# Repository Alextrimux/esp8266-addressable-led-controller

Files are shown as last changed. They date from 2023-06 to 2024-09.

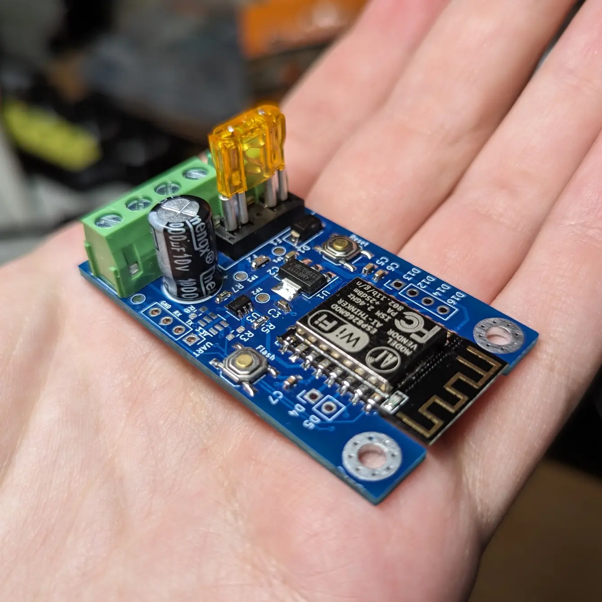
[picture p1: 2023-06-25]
pictures/board_1.jpg

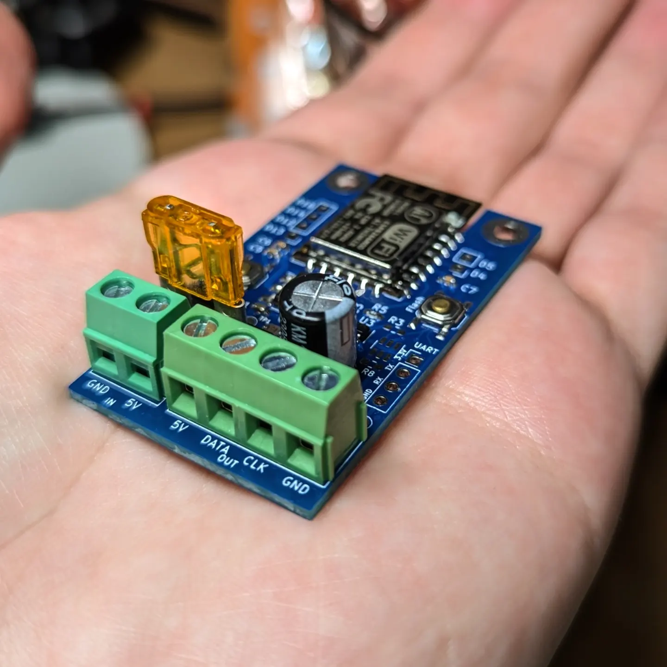
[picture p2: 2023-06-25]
pictures/board_2.jpg

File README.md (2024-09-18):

# esp8266-addressable-led-controller
The small hardware project of the addressable led controller on esp8266.

It is designed especially for using [WLED firmware](https://github.com/Aircoookie/WLED).

Features:
 - two-channel output for LED strip
 - reverse polarity protection
 - plug-in fuse
 - additional pins for extension

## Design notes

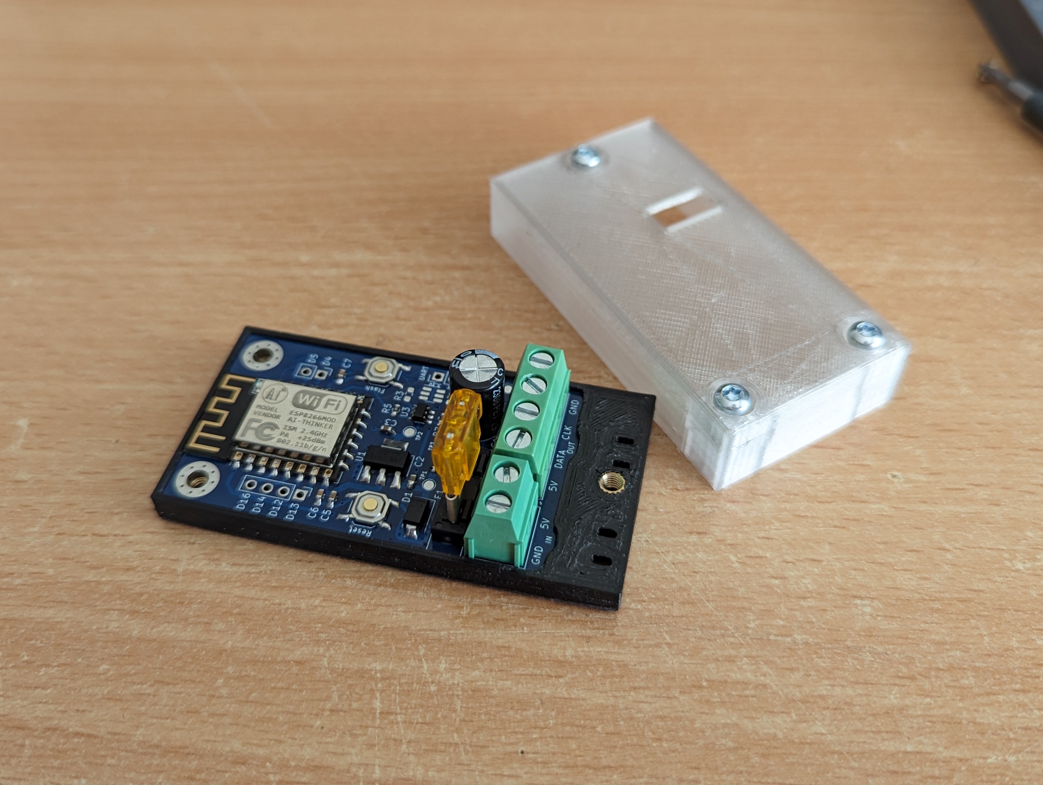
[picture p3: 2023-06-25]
pictures/case_open.jpg

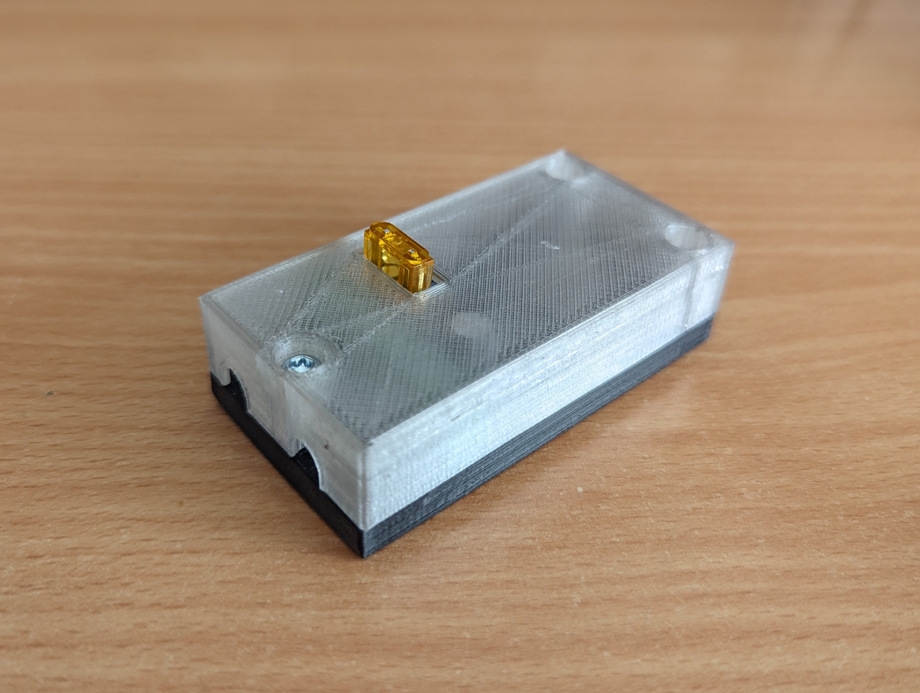
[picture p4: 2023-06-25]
pictures/case.jpg

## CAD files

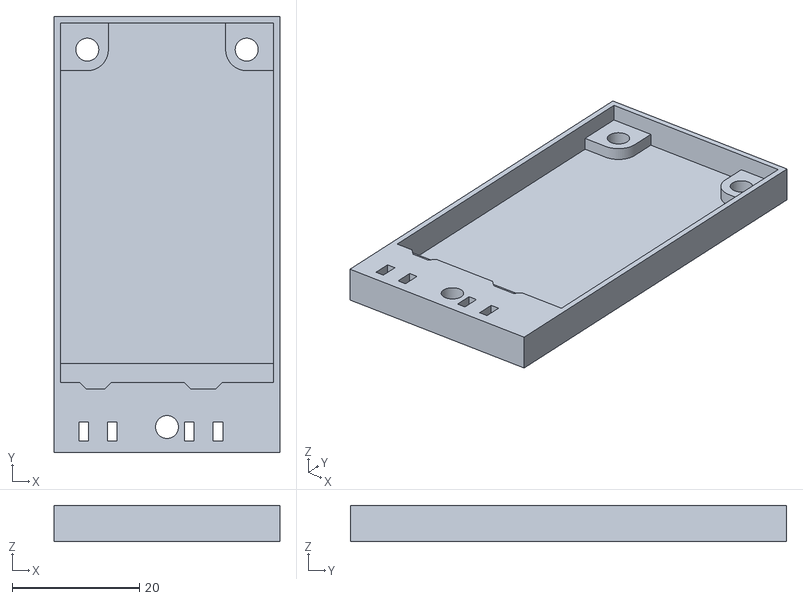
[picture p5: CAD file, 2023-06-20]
case/led-ctrl-top-v1.1.stl
35.4 x 68.4 x 5.70

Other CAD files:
case/led-ctrl-bottom.stl
case/esp8266-addressable-led-controller.f3d

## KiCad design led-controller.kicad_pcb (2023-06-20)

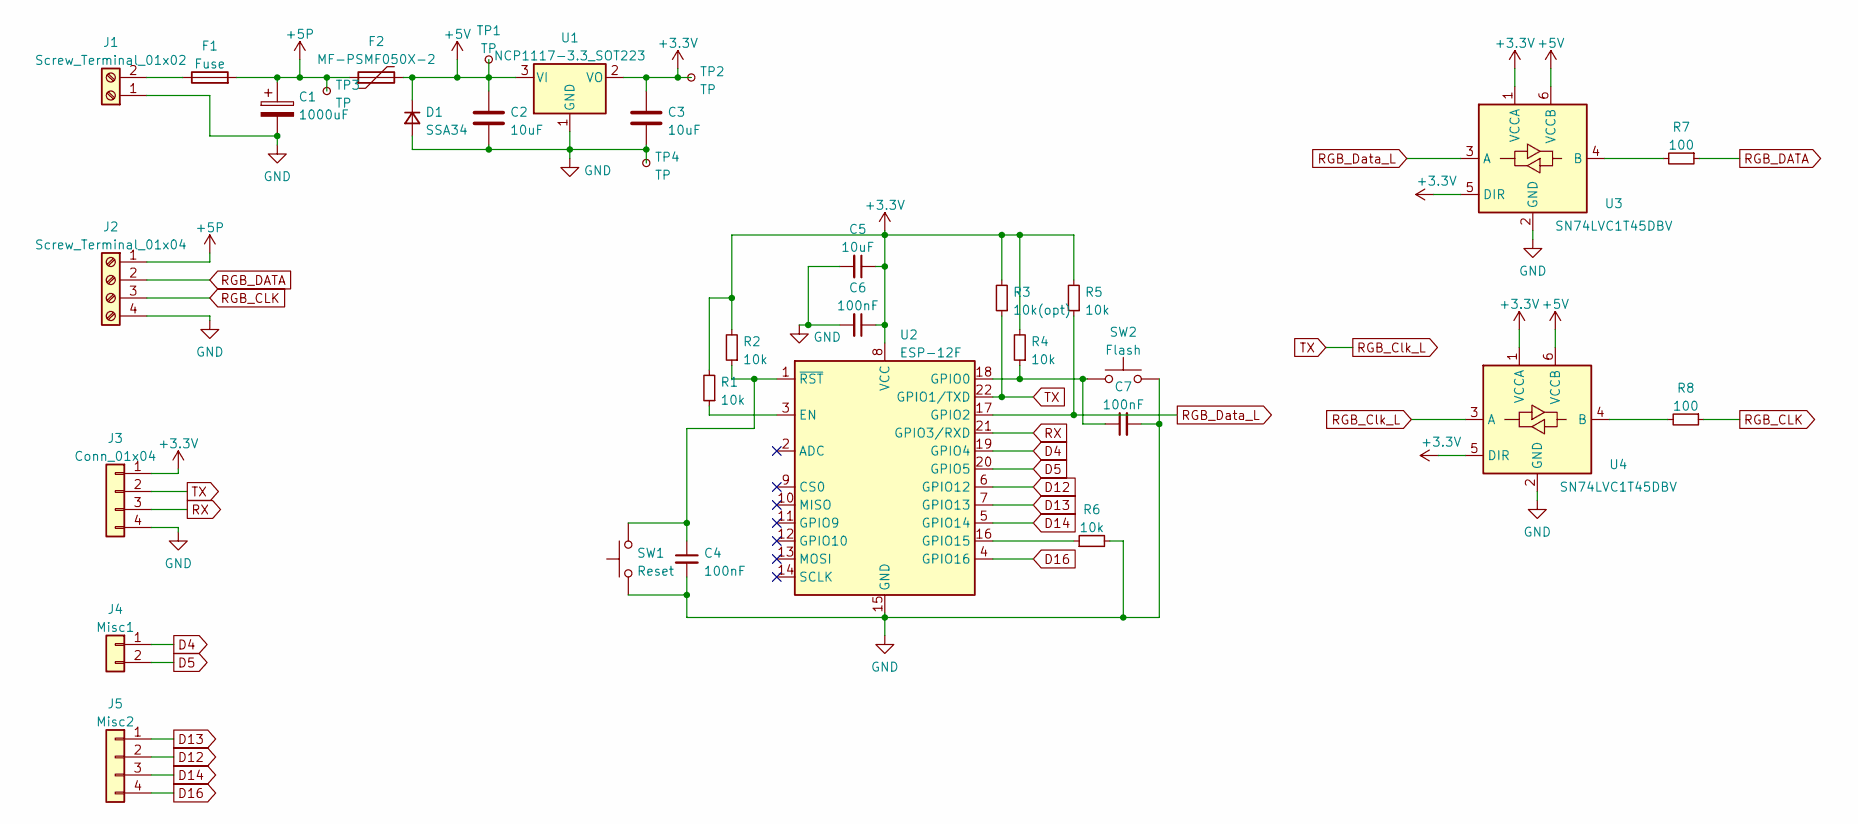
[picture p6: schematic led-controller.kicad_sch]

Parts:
C1: 1000uF; CP_Radial_D8.0mm_P3.50mm
C2, C3, C5: 10uF; C_0603_1608Metric_Pad1.08x0.95mm_HandSolder
C4, C6, C7: 100nF; C_0603_1608Metric_Pad1.08x0.95mm_HandSolder
D1: SSA34; D_SMA
F1: Fuse; XF-505P
F2: MF-PSMF050X-2; Fuse_0805_2012Metric_Pad1.15x1.40mm_HandSolder
J1: Screw_Terminal_01x02; TerminalBlock_bornier-2_P5.08mm
J2: Screw_Terminal_01x04; TerminalBlock_bornier-4_P5.08mm
J3: Conn_01x04; PinHeader_1x04_P2.54mm_Vertical
J4: Misc1; PinHeader_1x02_P2.54mm_Vertical
J5: Misc2; PinHeader_1x04_P2.54mm_Vertical
R1, R2, R4, R5, R6: 10k; R_0603_1608Metric_Pad0.98x0.95mm_HandSolder
R3: 10k(opt); R_0603_1608Metric_Pad0.98x0.95mm_HandSolder
R7, R8: 100; R_0603_1608Metric_Pad0.98x0.95mm_HandSolder
SW1: Reset; SW_SPST_TL3342
SW2: Flash; SW_SPST_TL3342
TP1, TP2, TP3, TP4: TP; TestPoint_Pad_D1.5mm
U1: NCP1117-3.3_SOT223; SOT-223-3_TabPin2
U2: ESP-12F; ESP-12E
U3, U4: SN74LVC1T45DBV; SOT-23-6

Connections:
+3V3: C3.1, C5.1, C6.1, J3.1, R1.2, R2.2, R3.2, R4.2, R5.2, TP2.1, U1.2 (VO), U2.8 (VCC), U3.1 (VCCA), U3.5 (DIR), U4.1 (VCCA), U4.5 (DIR)
+5P: C1.1, F1.2, F2.1, J2.1, TP3.1
+5V: C2.1, D1.1 (K), F2.2, TP1.1, U1.3 (VI), U3.6 (VCCB), U4.6 (VCCB)
D4: J4.1, U2.19 (GPIO4)
D5: J4.2, U2.20 (GPIO5)
D12: J5.2, U2.6 (GPIO12)
D13: J5.1, U2.7 (GPIO13)
D14: J5.3, U2.5 (GPIO14)
D16: J5.4, U2.4 (GPIO16)
GND: C1.2, C2.2, C3.2, C4.2, C5.2, C6.2, C7.2, D1.2 (A), J1.1, J2.4, J3.4, R6.2, SW1.1, SW2.2, TP4.1, U1.1 (GND), U2.15 (GND), U3.2 (GND), U4.2 (GND)
unnamed: C4.1, R2.1, SW1.2, U2.1 (~RST)
unnamed: C7.1, R4.1, SW2.1, U2.18 (GPIO0)
unnamed: F1.1, J1.2
unnamed: R1.1, U2.3 (EN)
unnamed: R6.1, U2.16 (GPIO15)
unnamed: R7.2, U3.4 (B)
unnamed: R8.2, U4.4 (B)
RGB_CLK: J2.3, R8.1
RGB_Clk_L: J3.2, R3.1, U2.22 (GPIO1/TXD), U4.3 (A)
RGB_DATA: J2.2, R7.1
RGB_Data_L: R5.1, U2.17 (GPIO2), U3.3 (A)
RX: J3.3, U2.21 (GPIO3/RXD)

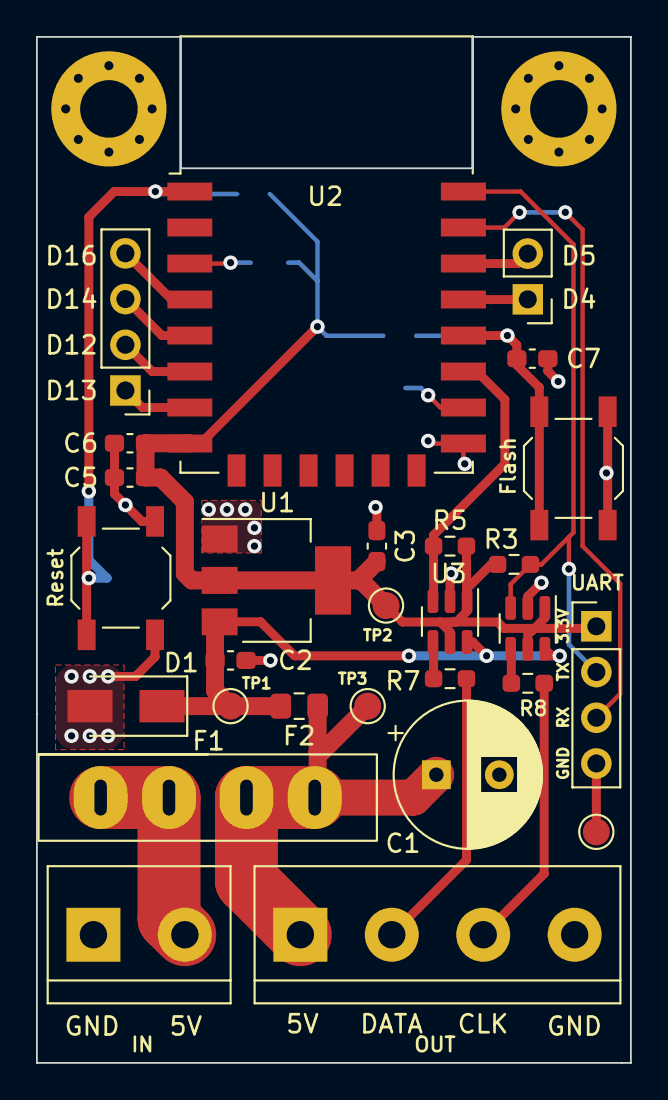
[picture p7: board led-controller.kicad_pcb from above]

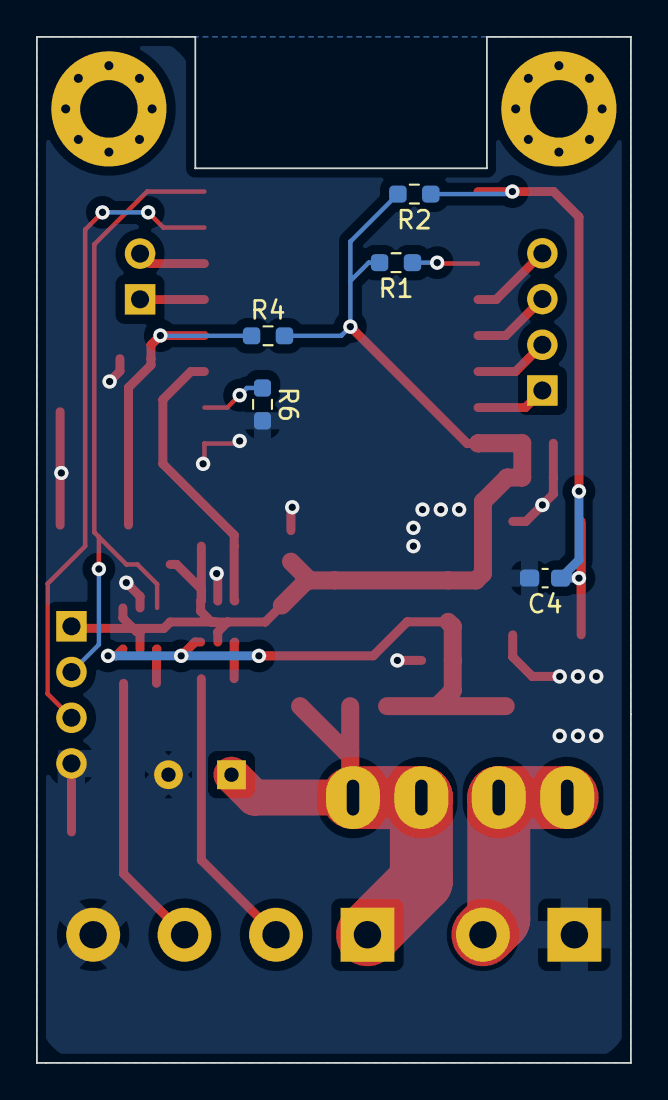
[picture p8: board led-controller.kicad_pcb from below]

Board: 2 copper layers, 33.0 x 57.0 mm, 33 parts (5 on the bottom side), 22 nets.

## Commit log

2023-05-30 Initialized KiCad project
    [led-controller.kicad_pcb, led-controller.kicad_sch]
2023-06-01 Designed schematic and PCB
    [led-controller.kicad_pcb, led-controller.kicad_sch]
2023-06-20 Created case for device. Added gerber files for PCB manufacturing.
    [esp8266-addressable-led-controller.f3d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]
2023-06-25 Upload pictures of assembled device
